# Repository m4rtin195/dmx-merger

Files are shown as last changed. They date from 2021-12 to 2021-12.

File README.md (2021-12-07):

# dmx-merger

A practical part of my bachelor thesis, a device based on AVR microcontrollers, which joins two DMX512 signal streams together.

The project consists of 2 MCUs:
- `ATmega324P` that serves as a *receiver*, and "master" controller in the device, and
- `ATmega8` that serves as a *sender*, generating output DMX <u>signal</u>

More in [Bachelor thesis theory](BP_Timko_final2.pdf) (chapter 5), or in [presentation](BP_prezentacia.pdf).
<br>
<p float="left">
  
  &nbsp; &nbsp;
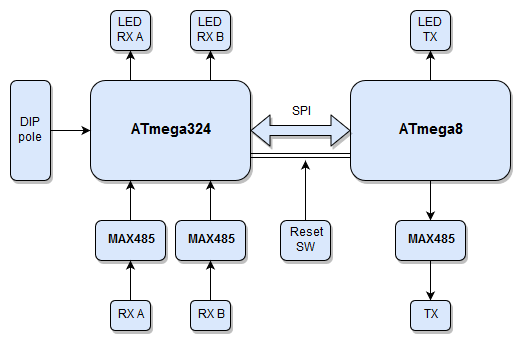
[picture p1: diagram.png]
   
</p>

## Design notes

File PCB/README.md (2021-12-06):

**Electronic scheme:**
<br><br>
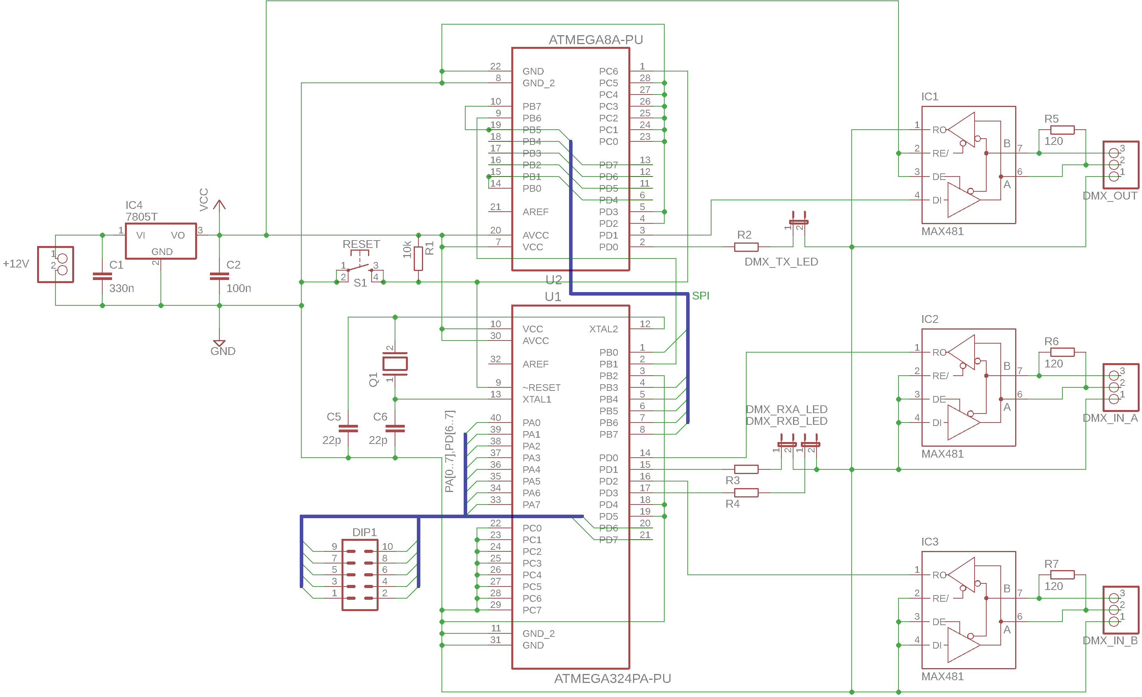
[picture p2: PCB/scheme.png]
scheme

<br>

**PCB board design:**
<br><br>
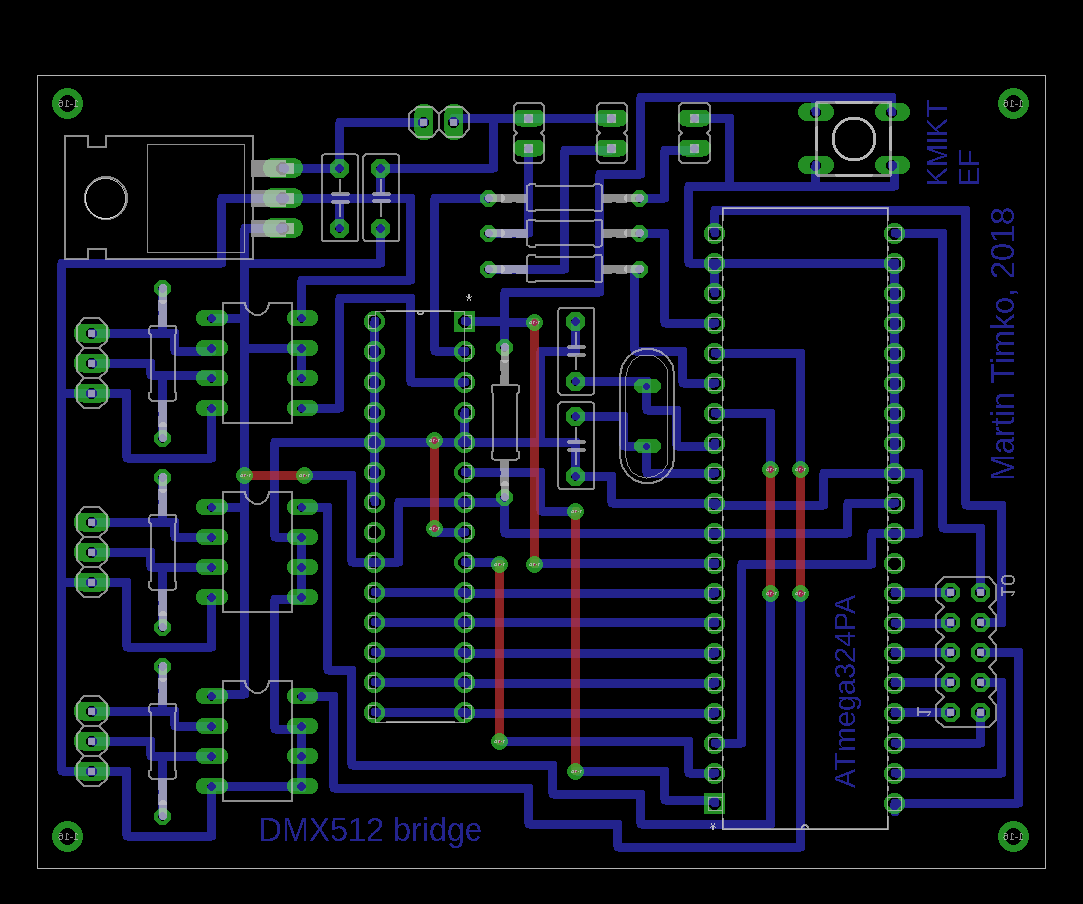
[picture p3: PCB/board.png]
board


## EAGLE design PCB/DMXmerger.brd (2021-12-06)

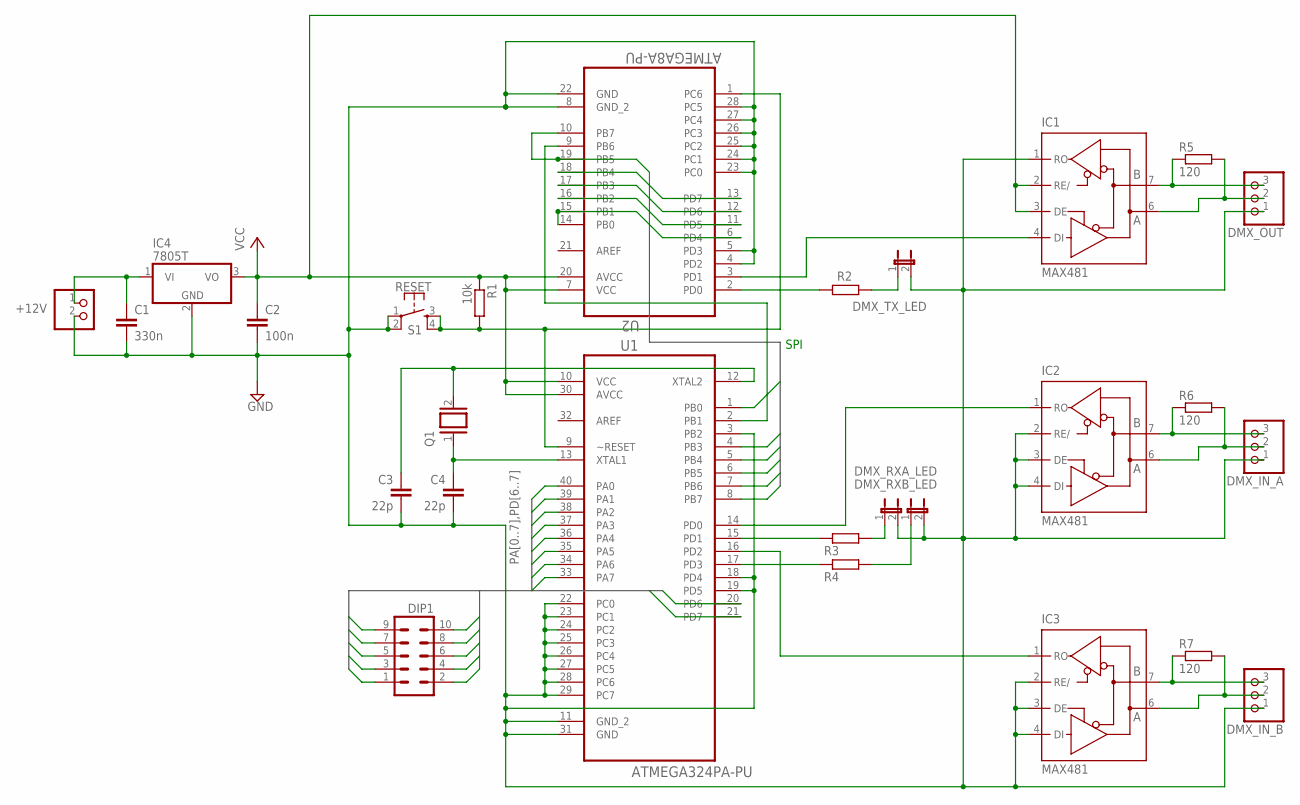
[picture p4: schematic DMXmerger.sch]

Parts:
+12V: PINHD-1X2; 1X02
C1: 330n; C5B3
C2: 100n; C5B3
C3, C4: 22p; C5B3
DIP1: MA05-2
DMX_IN_A: PINHD-1X3; 1X03
DMX_IN_B: PINHD-1X3; 1X03
DMX_OUT: PINHD-1X3; 1X03
DMX_RXA_LED: JP1E; JP1
DMX_RXB_LED: JP1E; JP1
DMX_TX_LED: JP1E; JP1
IC1, IC2, IC3: MAX481; DIL08
IC4: 7805T; TO220H
Q1: XTAL/S; QS
R1: 10k; 0207/12
R2, R3, R4: 250; 0207/12
R5, R6, R7: 120; 0207/12
S1: RESET; DTS-6
U1: ATMEGA324PA-PU; DIP254P1524X482-40
U2: ATMEGA8A-PU; DIP254P762X457-28

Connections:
1: DIP1.1, U1.37 (PA3)
2: DIP1.2, U1.38 (PA2)
3: DIP1.3, U1.36 (PA4)
4: DIP1.4, U1.39 (PA1)
5: DIP1.5, U1.35 (PA5)
6: DIP1.6, U1.40 (PA0)
7: DIP1.7, U1.34 (PA6)
8: DIP1.8, U1.20 (PD6)
9: DIP1.9, U1.33 (PA7)
10: DIP1.10, U1.21 (PD7)
GND: +12V.2, C1.2, C2.2, C3.2, C4.2, DMX_IN_A.1, DMX_IN_B.1, DMX_OUT.1, DMX_RXA_LED.2, DMX_RXB_LED.2, DMX_TX_LED.2, IC1.1 (RO), IC1.5 (GND), IC2.2 (RE/), IC2.3 (DE), IC2.4 (DI), IC2.5 (GND), IC3.2 (RE/), IC3.3 (DE), IC3.4 (DI), IC3.5 (GND), IC4.2 (GND), S1.1, S1.2, U1.3 (PB2), U1.11 (GND_2), U1.18 (PD4), U1.19 (PD5), U1.22 (PC0), U1.23 (PC1), U1.24 (PC2), U1.25 (PC3), U1.26 (PC4), U1.27 (PC5), U1.28 (PC6), U1.29 (PC7), U1.31 (GND), U2.4 (PD2), U2.5 (PD3), U2.8 (GND_2), U2.22 (GND), U2.23 (PC0), U2.24 (PC1), U2.25 (PC2), U2.26 (PC3), U2.27 (PC4), U2.28 (PC5)
LED: U1.1 (PB0), U2.6 (PD4)
MISO: U1.7 (PB6), U2.11 (PD5), U2.18 (PB4)
MOSI: U1.6 (PB5), U2.12 (PD6), U2.17 (PB3)
unnamed: DMX_TX_LED.1, R2.1
unnamed: DMX_IN_B.3, IC3.7 (B), R7.1
unnamed: R2.2, U2.2 (PD0)
unnamed: U1.2 (PB1), U2.9 (PB6)
unnamed: DMX_IN_B.2, IC3.6 (A), R7.2
unnamed: R1.2, S1.3, S1.4, U1.9 (~RESET), U2.1 (PC6)
unnamed: C4.1, Q1.1, U1.13 (XTAL1)
unnamed: +12V.1, C1.1, IC4.1 (VI)
unnamed: DMX_OUT.3, IC1.7 (B), R5.1
unnamed: DMX_IN_A.3, IC2.7 (B), R6.1
unnamed: DMX_IN_A.2, IC2.6 (A), R6.2
unnamed: IC1.4 (DI), U2.3 (PD1)
unnamed: DMX_OUT.2, IC1.6 (A), R5.2
unnamed: IC2.1 (RO), U1.14 (PD0)
unnamed: IC3.1 (RO), U1.16 (PD2)
unnamed: R3.2, U1.15 (PD1)
unnamed: R4.2, U1.17 (PD3)
unnamed: DMX_RXA_LED.1, R3.1
unnamed: C3.1, Q1.2, U1.12 (XTAL2)
unnamed: DMX_RXB_LED.1, R4.1
RST: U1.4 (PB3), U2.14 (PB0), U2.15 (PB1)
SCK: U1.8 (PB7), U2.10 (PB7), U2.19 (PB5)
SS: U1.5 (PB4), U2.13 (PD7), U2.16 (PB2)
VCC: C2.1, IC1.2 (RE/), IC1.3 (DE), IC1.8 (VCC), IC2.8 (VCC), IC3.8 (VCC), IC4.3 (VO), R1.1, U1.10 (VCC), U1.30 (AVCC), U2.7 (VCC), U2.20 (AVCC)

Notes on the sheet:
SPI

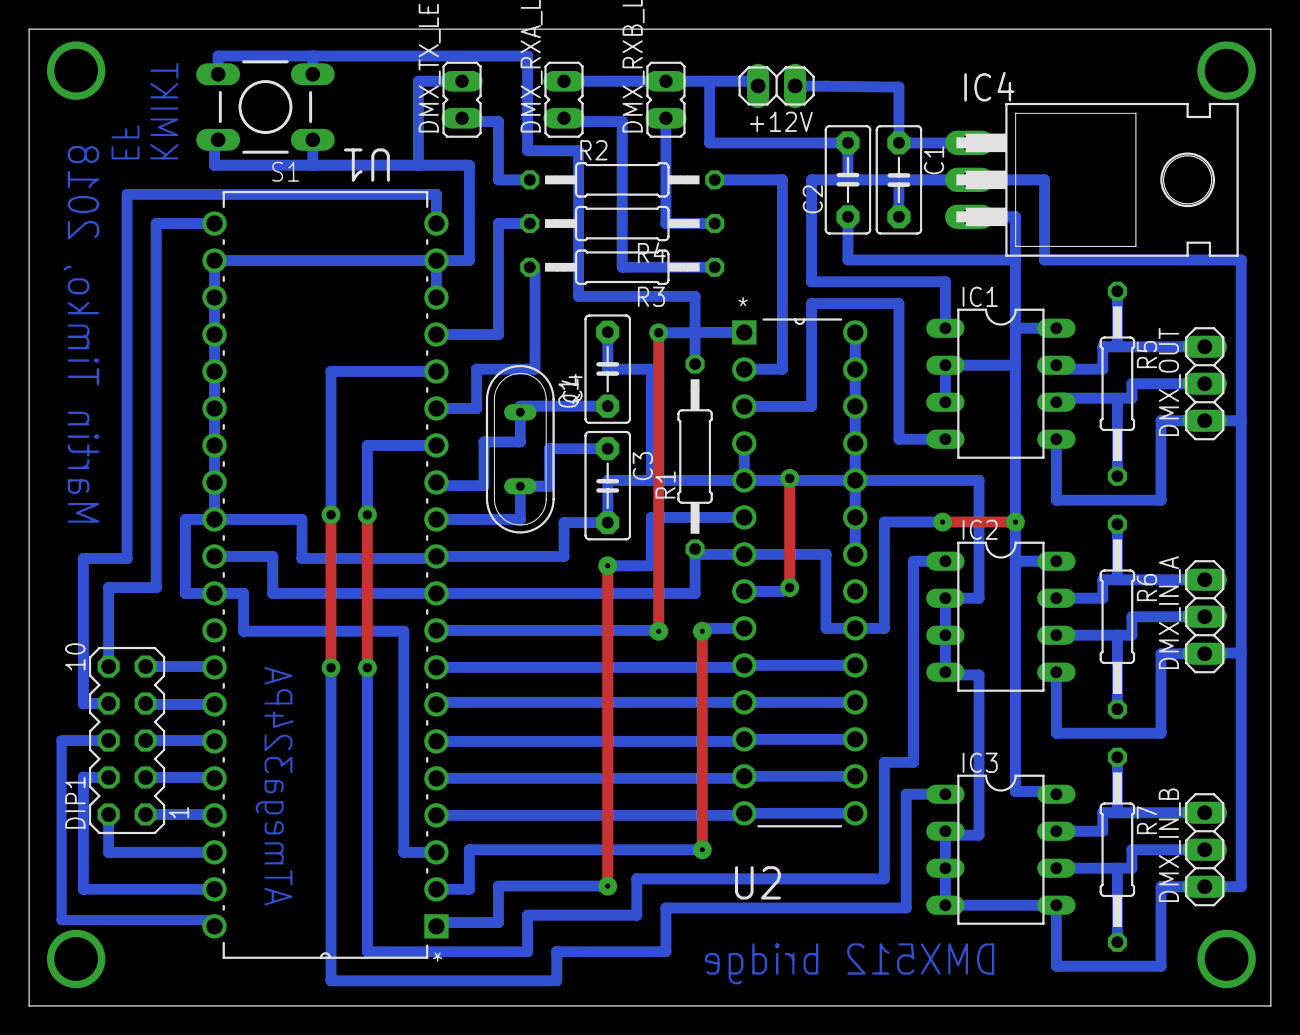
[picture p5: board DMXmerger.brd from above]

Board: 2 copper layers, 85.3 x 67.1 mm, 27 parts (0 on the bottom side), 38 nets.

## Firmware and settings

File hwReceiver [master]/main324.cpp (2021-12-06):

#include <avr/io.h>
#include <util/delay.h>
#include <avr/interrupt.h>
#include <limits.h>

#include "defines324.h"


/// MILLIS TIMER ///

volatile unsigned long ms = 0;

unsigned long int millis(void)
{
    return ms;
}

void millis_init(void)
{
    //Timer0_Initialization
    GTCCR = (1 << PSRSYNC); // reset prescaler
    TCCR0B |= (1 << CS01);  // prescalar = 8
    TIMSK0 |= (1 << TOIE0); // timer 0 interrupt enable
}

volatile uint8_t times = 0;

ISR(TIMER0_OVF_vect)    // 0,5ms
{
    times++;
    if(times==10)
        {
            ms++;
            times=0;
        }
    TCNT0 = 155;  //250 tickov
}
/// TIMER END ///


/// /////////////// DMX CONTROLLER ///////////////// ///

#define Calcprescale(B)     ( ( (((F_CPU)/8)/(B)) - 1 ) / 2 )


volatile uint8_t    dmxData[DMXSERIAL_MAX+1];    // Array of DMX values (raw) // Entry 0 will not be used, only exist for logical simplicity reason...
uint16_t            BORDER_ADDR;           // hranièná adresa medzi príjmaèmi

volatile uint8_t    _dmxRecvState1; // Current State of receiving DMX Bytes
volatile uint8_t    _dmxRecvState2;
volatile int        _dmxChannel1;   // the next channel byte to be sent.
volatile int        _dmxChannel2;
volatile unsigned long _gotLastPacket1 = 0; // the last time (using the millis function) a packet was received.
volatile unsigned long _gotLastPacket2 = 0;


void DMX_Receivers_init()
{
  // initialize global variables
  _dmxRecvState1, _dmxRecvState2 = IDLE; // initial state
  _dmxChannel1, _dmxChannel2 = 0;

  // initialize the DMX buffer
  for (int n = 0; n < DMXSERIAL_MAX+1; n++)
    dmxData[n] = 0;

  // Set baud-settings and data format
  uint16_t baud_setting = Calcprescale(DMXSPEED);

  UCSR0A = 0;
  UBRR0L = baud_setting;
  UBRR0H = baud_setting >> 8;
  UCSR0C = DMXFORMAT;

  UCSR1A = 0;
  UBRR1L = baud_setting;
  UBRR1H = baud_setting >> 8;
  UCSR1C = DMXFORMAT;

  // Enable receivers and Receive interrupts
  UCSR0B = (1<<RXEN0) | (1<<RXCIE0);
  UCSR1B = (1<<RXEN1) | (1<<RXCIE1);
} // init()


// Calculate how long no data packet was received
unsigned long noDataSince1()
{
    if(_gotLastPacket1 == 0) return LONG_MAX;
    unsigned long now = millis();
    return (now - _gotLastPacket1);
} // noDataSince()

// Calculate how long no data packet was received
unsigned long noDataSince2()
{
    if(_gotLastPacket2 == 0) return LONG_MAX;
    unsigned long now = millis();
    return (now - _gotLastPacket2);
} // noDataSince()


/******/

// This Interrupt Service Routine is called when a byte or frame error was received.
ISR(USART0_RX_vect)
{
  uint8_t  USARTstate = UCSR0A;         //get state before data!
  uint8_t  DmxByte    = UDR0;	        //get data
  uint8_t  DmxState   = _dmxRecvState1;	//just load once from SRAM to increase speed

  if (USARTstate & (1<<FE0)) //check for break
  {
      _dmxRecvState1 = BREAK; // break condition detected.
      _dmxChannel1 = 0;       // The next data byte is the start byte

  }
  else if (DmxState == BREAK)
  {
      if (DmxByte == 0)
      {
          _dmxRecvState1 = DATA;  // normal DMX start code detected
          _dmxChannel1 = 1;       // start with channel # 1
          _gotLastPacket1 = millis(); // remember current (relative) time in msecs.
      }
      else
      {
        _dmxRecvState1 = IDLE; // This might be a RDM command
      } // if
  }
  else if (DmxState == DATA)
  {
      if(_dmxChannel1 >= 1 && _dmxChannel1 < (signed)BORDER_ADDR)
        dmxData[_dmxChannel1] = DmxByte;	// store received data into dmx data buffer.

      _dmxChannel1++;
      if(_dmxChannel1>DMXSERIAL_MAX) DmxState = IDLE; //error
   } // if
} // ISR(USARTn_RX_vect)

/**/

ISR(USART1_RX_vect)
{
  uint8_t  USARTstate = UCSR1A;         //get state before data!
  uint8_t  DmxByte    = UDR1;	        //get data
  uint8_t  DmxState   = _dmxRecvState2;	//just load once from SRAM to increase speed

  if (USARTstate & (1<<FE1)) //check for break
  {
      _dmxRecvState2 = BREAK; // break condition detected.
      _dmxChannel2 = 0;       // The next data byte is the start byte
  }
  else if (DmxState == BREAK)
  {
      if (DmxByte == 0)
      {
          _dmxRecvState2 = DATA;  // normal DMX start code detected
          _dmxChannel2 = 1;       // start with channel # 1
          _gotLastPacket2 = millis(); // remember current (relative) time in msecs.
      }
      else
      {
        _dmxRecvState2 = IDLE; // This might be a RDM command
      } // if
  }
  else if (DmxState == DATA)
  {
      if(!!(PINA & (1 << SHIFT_PIN)))   //shift off
      {
        if(_dmxChannel2 >= (signed)BORDER_ADDR && _dmxChannel2 <= DMXSERIAL_MAX)
            dmxData[_dmxChannel2] = DmxByte;	// store received data into dmx data buffer.
      }
      else                              //shift on
      {
        if(_dmxChannel2 >= 1 && _dmxChannel2 < (signed)BORDER_ADDR)
            dmxData[_dmxChannel2+BORDER_ADDR] = DmxByte;
      }

      _dmxChannel2++;
      if(_dmxChannel2>DMXSERIAL_MAX) DmxState = IDLE; //error
   } // if
} // ISR(USARTn_RX_vect)


/// END OF DMX PART /// /////////////////////////////////////////////////////////////





/// BEGINNING OF SPI PART ///

volatile unsigned int SPIchannel;
volatile bool inprogress;


void initSPI(void)
{
    SPI_PORT |= (1<<DD_SS);     //set SS high, inak nepovoli nastavenie MSTR
    SPI_DDR |= (1<<DD_MOSI) | (1<<DD_SCK) | (1<<DD_SS) | (1 << DD_RSTPIN) ; // SCK, MOSI and SS and RST as outputs
    SPI_DDR &= ~(1<<DD_MISO);   // MISO as input
    SPI_PORT |= (1 << DD_MISO); // enable pull-up on MISO

    //SPCR0 |= (1 << SPIE0);    // SPI interrupt enable
    SPCR0 |= (1 << SPE0);       // SPI enable
    SPCR0 |= (1 << MSTR0);      // Set as master
    SPCR0 &= ~(1<< DORD0);      // Data Order MSB first
    //SPSR0 |= (1 << SPI2X0);   // double speed enable

    SPCR0 |= (1<<SPR00);        // divide clock by 64

    inprogress = false;
}

void writeByteSPI()
{
    if(SPIchannel == 0)
    {
        SPI_PORT |= (1 << DD_RSTPIN);
        SPI_PORT &= ~(1 << DD_SS);
        SPDR0 = 0;
        while(!(SPSR0 & (1<<SPIF0)));
        SPI_PORT |=  (1 << DD_SS) | (1 << DD_RSTPIN);
        SPIchannel++;
    }
    else
    {
        SPI_PORT &= ~((1 << DD_SS) | (1 << DD_RSTPIN));
        SPDR0 = dmxData[SPIchannel++];	// Nahraj bajt do SPI dátového registra
        while(!(SPSR0 & (1<<SPIF0))); 	// Cakaj na ukoncenie prenosu
        SPI_PORT |=  (1 << DD_SS);
    }
    if(SPIchannel > DMXSERIAL_MAX) SPIchannel = 0;
}

void writeByteSPI(unsigned char byte)
{
    SPI_PORT &= ~(1 << DD_SS);
    SPDR0 = byte;					// Nahraj bajt do SPI dátového registra
    while(!(SPSR0 & (1<<SPIF0))); 	// Cakaj na ukoncenie prenosu
    SPI_PORT |=  (1 << DD_SS);
}


/// END OF PERIPHERIALS ////


uint16_t getAddr(void)
{
    uint16_t addr;
    addr = ( ((!(PINA & (1 << PA3))) << 0) | ((!(PINA & (1 << PA2))) << 1) | ((!(PINA & (1 << PA4))) << 2) | ((!(PINA & (1 << PA1))) << 3) | \
             ((!(PINA & (1 << PA5))) << 4) | ((!(PINA & (1 << PA0))) << 5) | ((!(PINA & (1 << PA6))) << 6) | ((!(PIND & (1 << PD6))) << 7) ) ;
    return addr;
}


int main(void)
{
    //OSCCAL = 0x49;  ///odmerat - OK na intRC

    DDRB |= (1 << DD_LEDPIN);   //set as output (signalizacia tx led)
    DDRD |= (1 << RXA_LED);     //set as output (leds)
    DDRD |= (1 << RXB_LED);

    //DIP input setting
    DDRA = 0x00;            //as input //dip
    PORTA = 0xFF;           //pullup //dip
    DDRD &= ~((1<<PD6) | (1<<KEEP_PIN)); //dip 8,10
    PORTD |= (1<<PD6) | (1<<KEEP_PIN);   //pullups
    //

    //inits
    millis_init();
    initSPI();
	DMX_Receivers_init();
	sei();


	while(1)
    {
        _delay_us(30);
        BORDER_ADDR = getAddr();
        writeByteSPI();

        if(!!(PIND & (1 << KEEP_PIN)))
        {
            if(noDataSince1()>1000)
            {
                for(int i=1; i<BORDER_ADDR; i++)
                    dmxData[i] = 0;
            }
            if(noDataSince2()>1000)
            {
                for(int i=BORDER_ADDR; i<DMXSERIAL_MAX; i++)
                    dmxData[i] = 0;
            }
        }

        //refresh led state
        if(noDataSince1()<1000) PORTD |= (1 << RXA_LED);
        else PORTD &= ~(1<<RXA_LED);
        if(noDataSince2()<1000) PORTD |= (1 << RXB_LED);
        else PORTD &= ~(1<<RXB_LED);

        //signal pre tx led
        if(noDataSince1()<1000 || noDataSince2()<1000)
            PORTB |= (1 << DD_LEDPIN);
        else
            PORTB &= ~(1 << DD_LEDPIN);
	}

	return 0;
}

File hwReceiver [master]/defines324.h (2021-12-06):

//#ifndef defines32_h
//#define defines32_h

/// DMX controller defines (USART)
//#define UCSRnA UCSR0A  // USART Control and Status Register A
//    #define TXCn   TXC0    // Transmit buffer clear
//    #define UDREn  UDRE0   // USART Data Ready
//    #define FEn    FE0     // Frame Error
//
//#define UCSRnB UCSR0B  // USART Control and Status Register B
//    #define RXCIEn RXCIE0  // Enable Receive Complete Interrupt
//    #define TXCIEn TXCIE0  // Enable Transmission Complete Interrupt
//    #define UDRIEn UDRIE0  // Enable Data Register Empty Interrupt
//    #define RXENn  RXEN0   // Enable Receiving
//    #define TXENn  TXEN0   // Enable Sending
//
//#define UCSRnC UCSR0C  // USART Control and Status Register C
//    #define USBSn  USBS0   // Stop bit select 0=1bit, 1=2bits
//    #define UCSZn0 UCSZ00  // Character size 00=5, 01=6, 10=7, 11=8 bits
//    #define UPMn0  UPM00   // Parity setting 00=N, 10=E, 11=O
//
//#define UBRRn  UBRR   // USART Baud Rate Register
//    #define UBRRnH UBRR0H  // USART Baud Rate Register High
//    #define UBRRnL UBRR0L  // USART Baud Rate Register Low
//
//#define UDRn   UDR0    // USART Data Register

#define USARTn_TX_vect   USART_TXC_vect  // Interrupt Data sent

// formats for serial transmission
//#define SERIAL_8N1  ((1<<URSEL) | (0<<USBSn) | (0<<UPMn0) | (3<<UCSZn0)) //unused
#define SERIAL_8N2  ((1<<USBS0) | (0<<UPM00) | (3<<UCSZ00))
#define SERIAL_8E1  ((0<<USBS0) | (2<<UPM00) | (3<<UCSZ00))
//#define SERIAL_8E2  ((1<<URSEL) | (1<<USBSn) | (2<<UPMn0) | (3<<UCSZn0)) //unused


// the break timing is 10 bits (start + 8 data + parity) of this speed
// the mark-after-break is 1 bit of this speed plus approx 6 usec
// 100000 bit/sec is good: gives 100 usec break and 16 usec MAB
// 1990 spec says transmitter must send >= 92 usec break and >= 12 usec MAB
// receiver must accept 88 us break and 8 us MAB
#define BREAKSPEED     100000
#define DMXSPEED       250000
#define BREAKFORMAT    SERIAL_8E1   // 1 stop bit and 8 bit character size, even parity
#define DMXFORMAT      SERIAL_8N2   // 2 stop bits and 8 bit character size, no parity


#define DMXSERIAL_MAX 512

typedef enum {IDLE, BREAK, DATA} DMXReceivingState;


/// ////////////////////////////////////////////////// ///
/// SPI PART ///

//ATmega324 as master
#define SPI_DDR     DDRB
#define SPI_PORT    PORTB
#define DD_MOSI     PB5
#define DD_MISO     PB6
#define DD_SCK      PB7
#define DD_SS       PB4
//aux_delay_us(40);
#define DD_LEDPIN      PB0
#define DD_RSTPIN      PB3

/// ////////////////////////////////////////////////// ///

#define SHIFT_PIN   PA7     // DIP9
#define KEEP_PIN    PD7     // DIP10

#define RXA_LED     PD1
#define RXB_LED     PD3
//#endif

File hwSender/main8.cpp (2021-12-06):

#include <avr/io.h>
#include <util/delay.h>
#include <avr/interrupt.h>
#include <limits.h>

#include "defines8.h"


/// /////////////// DMX CONTROLLER ///////////////// ///

#define Calcprescale(B)     ( ( (((F_CPU)/16)/(B)) - 1 )  )


uint8_t  dmxData[DMXSERIAL_MAX+1];  // Entry 0 will never be used for DMX data but will store the startbyte
int     _dmxChannel;                // the next channel byte to be sent.
bool    tx_enabled;

/** ----- forwards ----- **/

void _DMXSerialSetBaud(uint16_t baud_setting, uint8_t format);
void _DMXSerialWriteByte(uint8_t data);


void DMX_Controller_init()
{
  // initialize global variables
  _dmxChannel = 0;

  // initialize the DMX buffer
  for (int n = 0; n < DMXSERIAL_MAX+1; n++)
    dmxData[n] = 0;

  // Enable transmitter and interrupt
  UCSRB = (1<<TXEN) | (1<<TXCIE);

  // Start sending a BREAK and loop (forever) in UDRE ISR
  _DMXSerialSetBaud(Calcprescale(BREAKSPEED), BREAKFORMAT);
  _DMXSerialWriteByte((uint8_t)0);
  _dmxChannel = 0;
} // init()

// Terminale operation
void DMX_Controller_term(void)
{
  // Disable all USART Features, including Interrupts
  UDR = 0;
  UCSRA, UCSRB, UCSRC = 0;
  UBRRL, UBRRH = 0;
} // term()

/** ----- internal functions and interrupt implementations ----- **/

// Initialize the Hardware serial port with the given baud rate
// using 8 data bits, no parity, 2 stop bits for data
// and 8 data bits, even parity, 1 stop bit for the break
void _DMXSerialSetBaud(uint16_t baud_setting, uint8_t format)
{
  UCSRA = 0;
  UBRRH = baud_setting >> 8;
  UBRRL = baud_setting;
  UCSRC = format;
} // _DMXSerialSetBaud

// send the next byte after current byte was sent completely.
void _DMXSerialWriteByte(uint8_t data)
{
  // putting data into buffer sends the data
  UDR = data;
} // _DMXSerialWrite


/******/

// Interrupt service routines that are called when the actual byte was sent.
// When changing speed (for sending break and sending start code) we use TX finished interrupt
// which occurs shortly after the last stop bit is sent
// When staying at the same speed (sending data bytes) we use data register empty interrupt
// which occurs shortly after the start bit of the *previous* byte
// When sending a DMX sequence it just takes the next channel byte and sends it out.
// In DMXController mode when the buffer was sent completely the DMX sequence will resent, starting with a BREAK pattern.
// In DMXReceiver mode this interrupt is disabled and will not occur.
ISR(USARTn_TX_vect)
{
  if (_dmxChannel == -1)
  {
    // this interrupt occurs after the stop bits of the last data byte
    // start sending a BREAK and loop forever in ISR
    _DMXSerialSetBaud(Calcprescale(BREAKSPEED), BREAKFORMAT);
    _DMXSerialWriteByte((uint8_t)0);
    _dmxChannel = 0;

  }
  else if (_dmxChannel == 0)
  {
    // this interrupt occurs after the stop bits of the break byte
    // now back to DMX speed: 250000baud
    _DMXSerialSetBaud(Calcprescale(DMXSPEED), DMXFORMAT);
    // take next interrupt when data register empty (early)
    UCSRB = (1<<TXEN) | (1<<UDRIE);
    // write start code
    _DMXSerialWriteByte((uint8_t)0);
    _dmxChannel = 1;

  } // if
} // ISR(USARTn_TX_vect)


// this interrupt occurs after the start bit of the previous data byte
ISR(USARTn_UDRE_vect)
{
  _DMXSerialWriteByte(dmxData[_dmxChannel++]);

  if (_dmxChannel > DMXSERIAL_MAX)
  {
    _dmxChannel   = -1; // this series is done. Next time: restart with break.
    // get interrupt after this byte is actually transmitted
    UCSRB = (1<<TXEN) | (1<<TXCIE); /// potrebne?????
  } // if
} // ISR(USARTn_UDRE_vect)


/// END OF DMX PART ///






/// BEGINNING OF SPI PART ///

volatile unsigned int SPIchannel;
volatile unsigned char receivedByte;


void initSPI(void)
{
    SPI_DDR |= (1<<DD_MISO);    // set MISO as output
    SPI_DDR &= ~((1 << DD_SCK) | (1 << DD_MOSI) | (1 << DD_SS) | (1 << DD_RSTPIN)); // set other as inputs
    SPI_PORT |= (1 << DD_SCK) | (1 << DD_MOSI) | (1 << DD_SS) | (1 << DD_RSTPIN);  // set pull-ups

    SPCR |= (1<<SPE);       // SPI enable
    SPCR |= (1<<SPIE);      // SPI interrupt enable
    SPCR &= ~(1<<MSTR);     // Set as slave
    SPCR &= ~(1<<DORD);     // Data Order MSB first

    receivedByte = 0;
    SPIchannel = 0;
}


ISR(SPI_STC_vect)
{
    if(!!((SPI_PIN & (1<<DD_RSTPIN))) && (SPDR == 0)) //dvojita negacia stavu vstup.pinu
    {
        SPIchannel = 1;
    }
    else
    {
        dmxData[SPIchannel++] = SPDR;
        SPDR = 0;
    }
    if(SPIchannel > DMXSERIAL_MAX)
        SPIchannel = 0;
}

/// END OF PERIPHERIALS ////




int main()
{
    //OSCCAL = 0xAC;

    DDRD |= (1 << TX_LED);     //set as output
    DDRD &= ~(1<<DD_LEDPIN);   //set as input

    tx_enabled = false;
    initSPI();
    //DMX_Controller_init();

    sei();

    while(1)
    {
        _delay_us(30);

        if(PIND & (1 << DD_LEDPIN)) //vysielat
        {
            if(tx_enabled == false)
            {
                tx_enabled = true;
                DMX_Controller_init();
            }
            PORTD |= (1 << TX_LED);
        }
        else                        //stop vysielania
        {
            tx_enabled = false;
            DMX_Controller_term();
            PORTD &= ~(1 << TX_LED);
        }
    }

    return 0;
}
